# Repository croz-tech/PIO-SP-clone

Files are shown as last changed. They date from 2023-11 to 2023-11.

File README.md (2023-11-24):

# PIO-SP-clone
A clone of the 1980s Cambridge Microelectronics (Camel Products) PIO-SP providing 8 latched inputs and 8 latched outputs for the ZX Spectrum range of machines on port 63 (decimal).

# From the original User Notes
This parallel input/output card allows the Sinclair Spectrum personal computer to control external hardware such as relays, indicators, transducers and motors.
Eight output channels and eight input channels are provided.  Both channels employ latches to obtain stable readings.  They may be used for eight bit bytes or to read or control single independent devices.  PIO-SP is located in the Spectrum's I/O map at address 63 (decimal). Both ports have the same address so BASIC or machine code IN and OUT commands can be used.  For example, OUT 63,85 will put an alternate pattern of ones and zeroes at the output port.  The input port has provision for strobing-in the exteral data.  If data is meant to be continuously read in the Spectrum, without attention from the outside then the ~STB pin should be connected to GND (fit JP1).  The Spectrum strobes the input latch when executing an IN command and therefore reads whatever is present in the 8 bit latch, while strobing in the new data at the same time.  All inputs and outputs are TTL compatibe and have high drive capabilities.
The unit plugs into the rear of the Spectrum. (note this unit does not currently include the male pass-through edge connector of the original)
Header connections are identical to the Camel Products PIO for ZX81. For convenience, in addition to the DIP-16 headers, a 20-way IDC header is also provided for more convenient connection/disconnection.

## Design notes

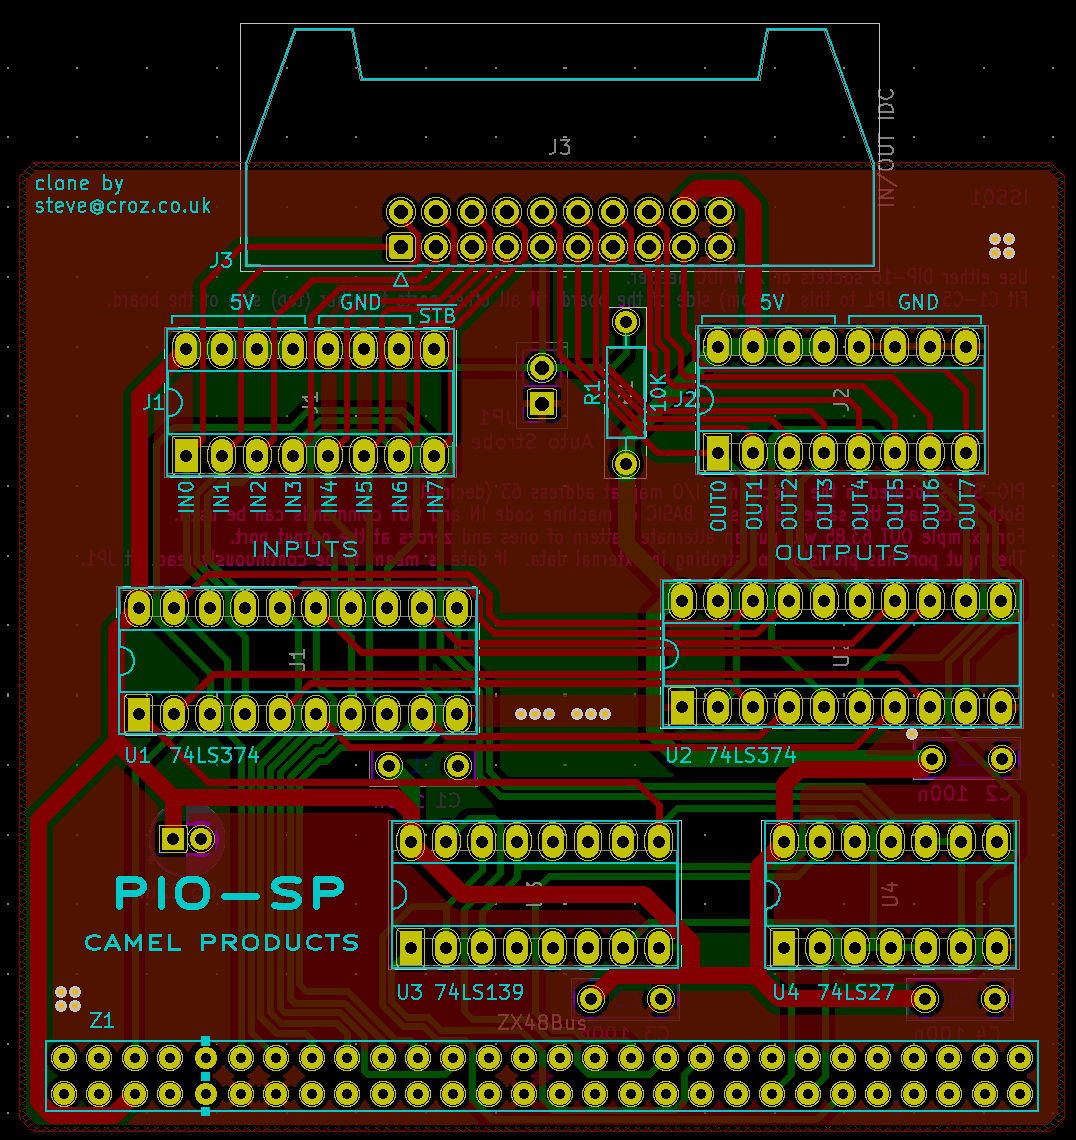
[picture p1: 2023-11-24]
PCB.png

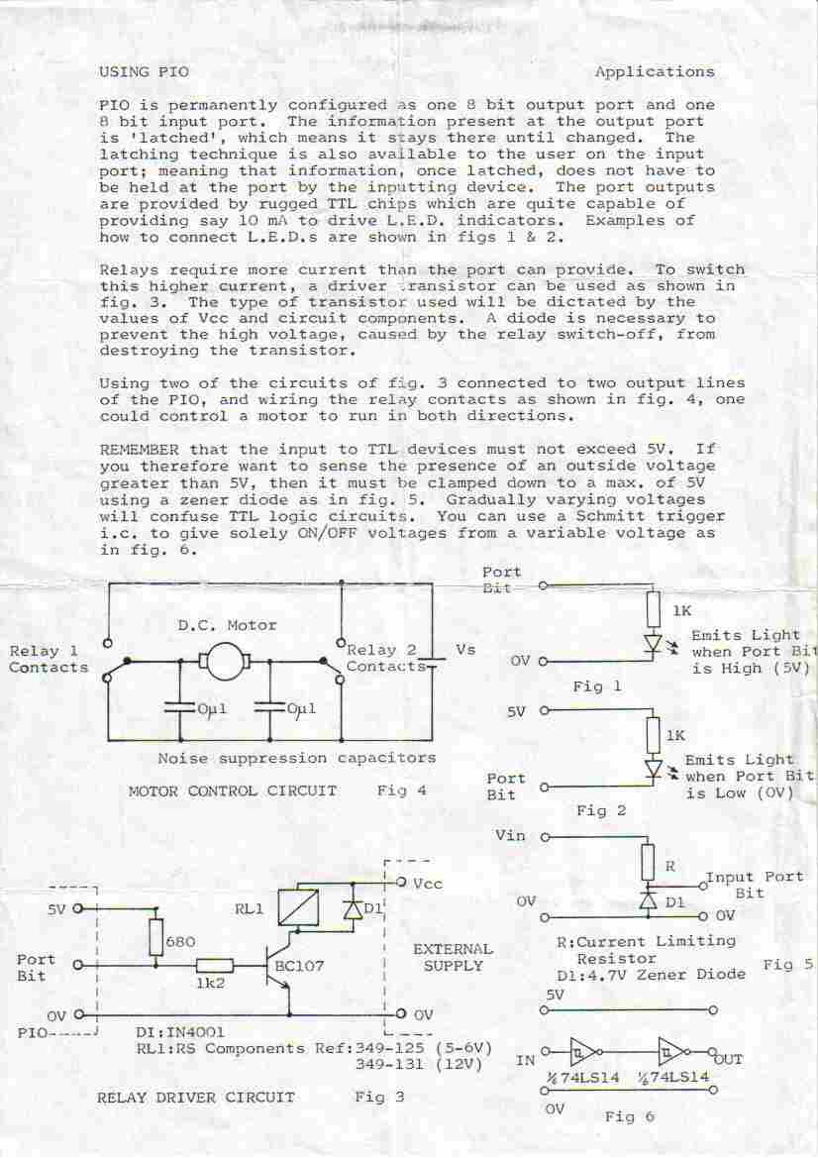
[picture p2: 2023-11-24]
original docs/Camel-PIO-SP-2.jpg

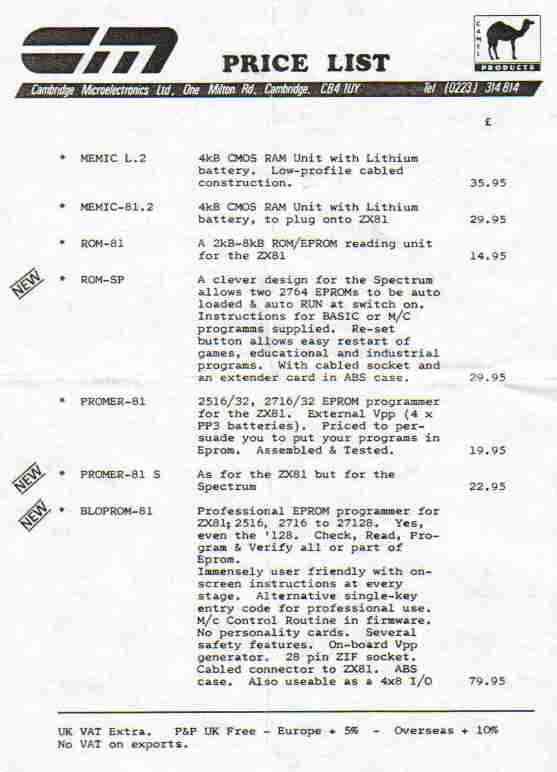
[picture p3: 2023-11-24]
original docs/Camel-Prices1.jpg

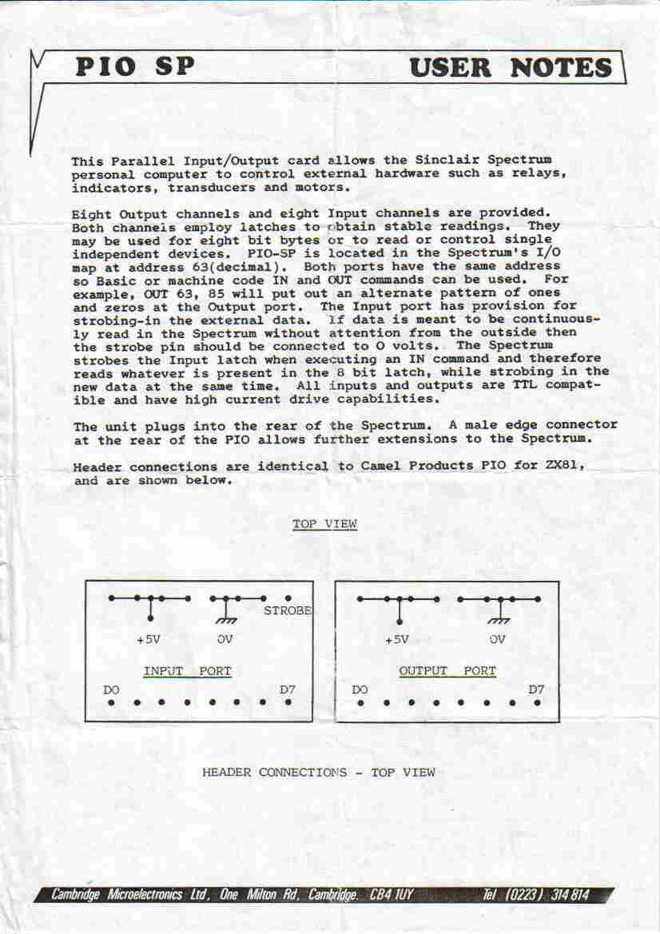
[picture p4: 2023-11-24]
original docs/Camel-PIO-SP-1.jpg

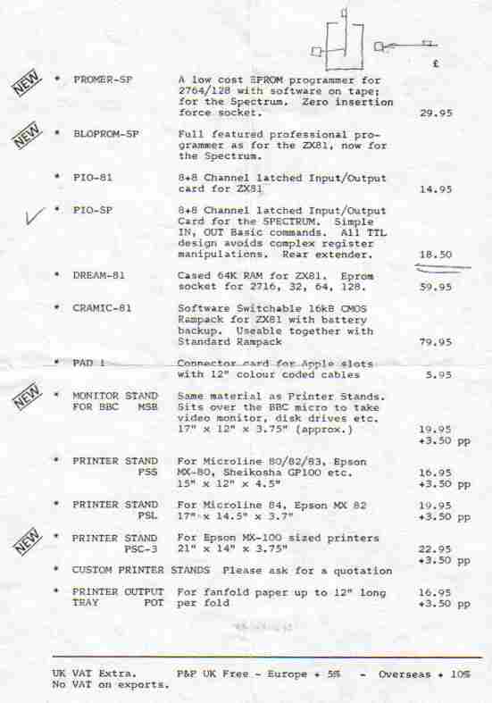
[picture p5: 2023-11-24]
original docs/Camel-Prices2.jpg

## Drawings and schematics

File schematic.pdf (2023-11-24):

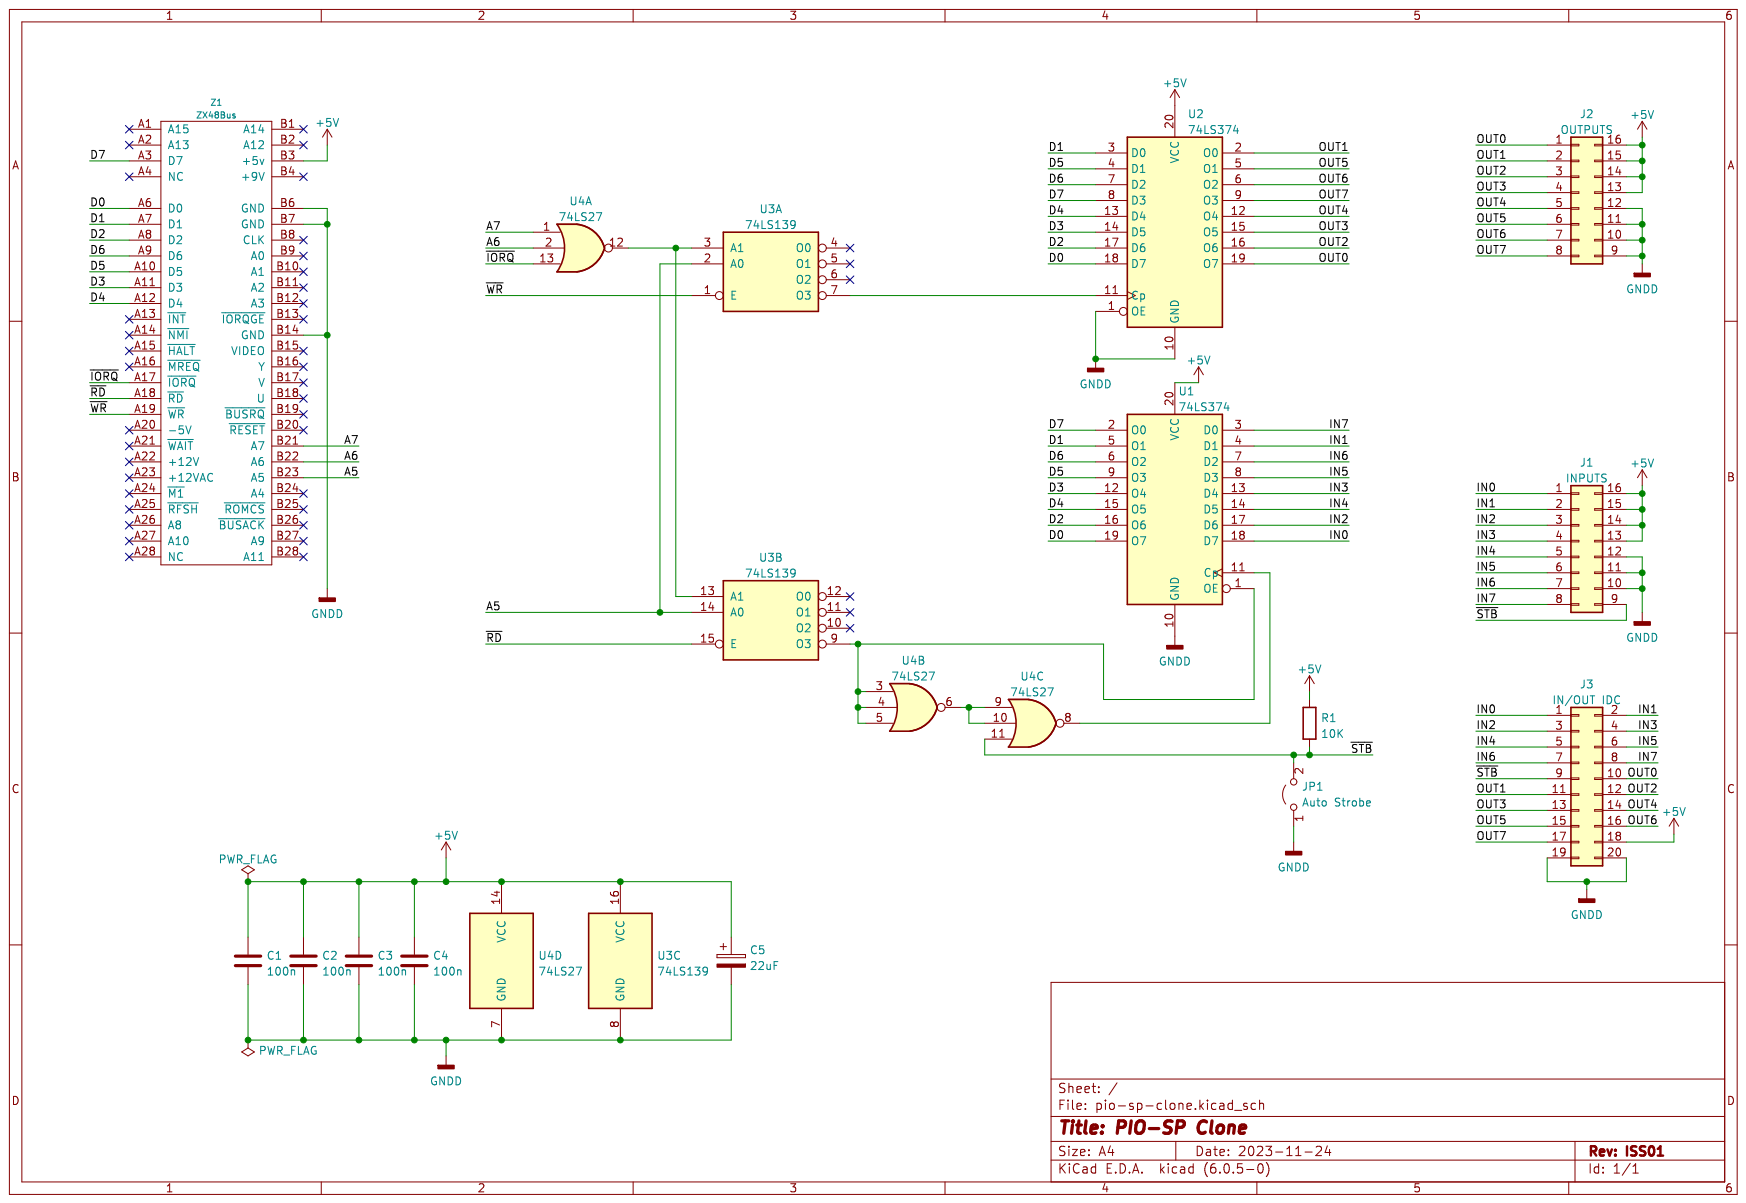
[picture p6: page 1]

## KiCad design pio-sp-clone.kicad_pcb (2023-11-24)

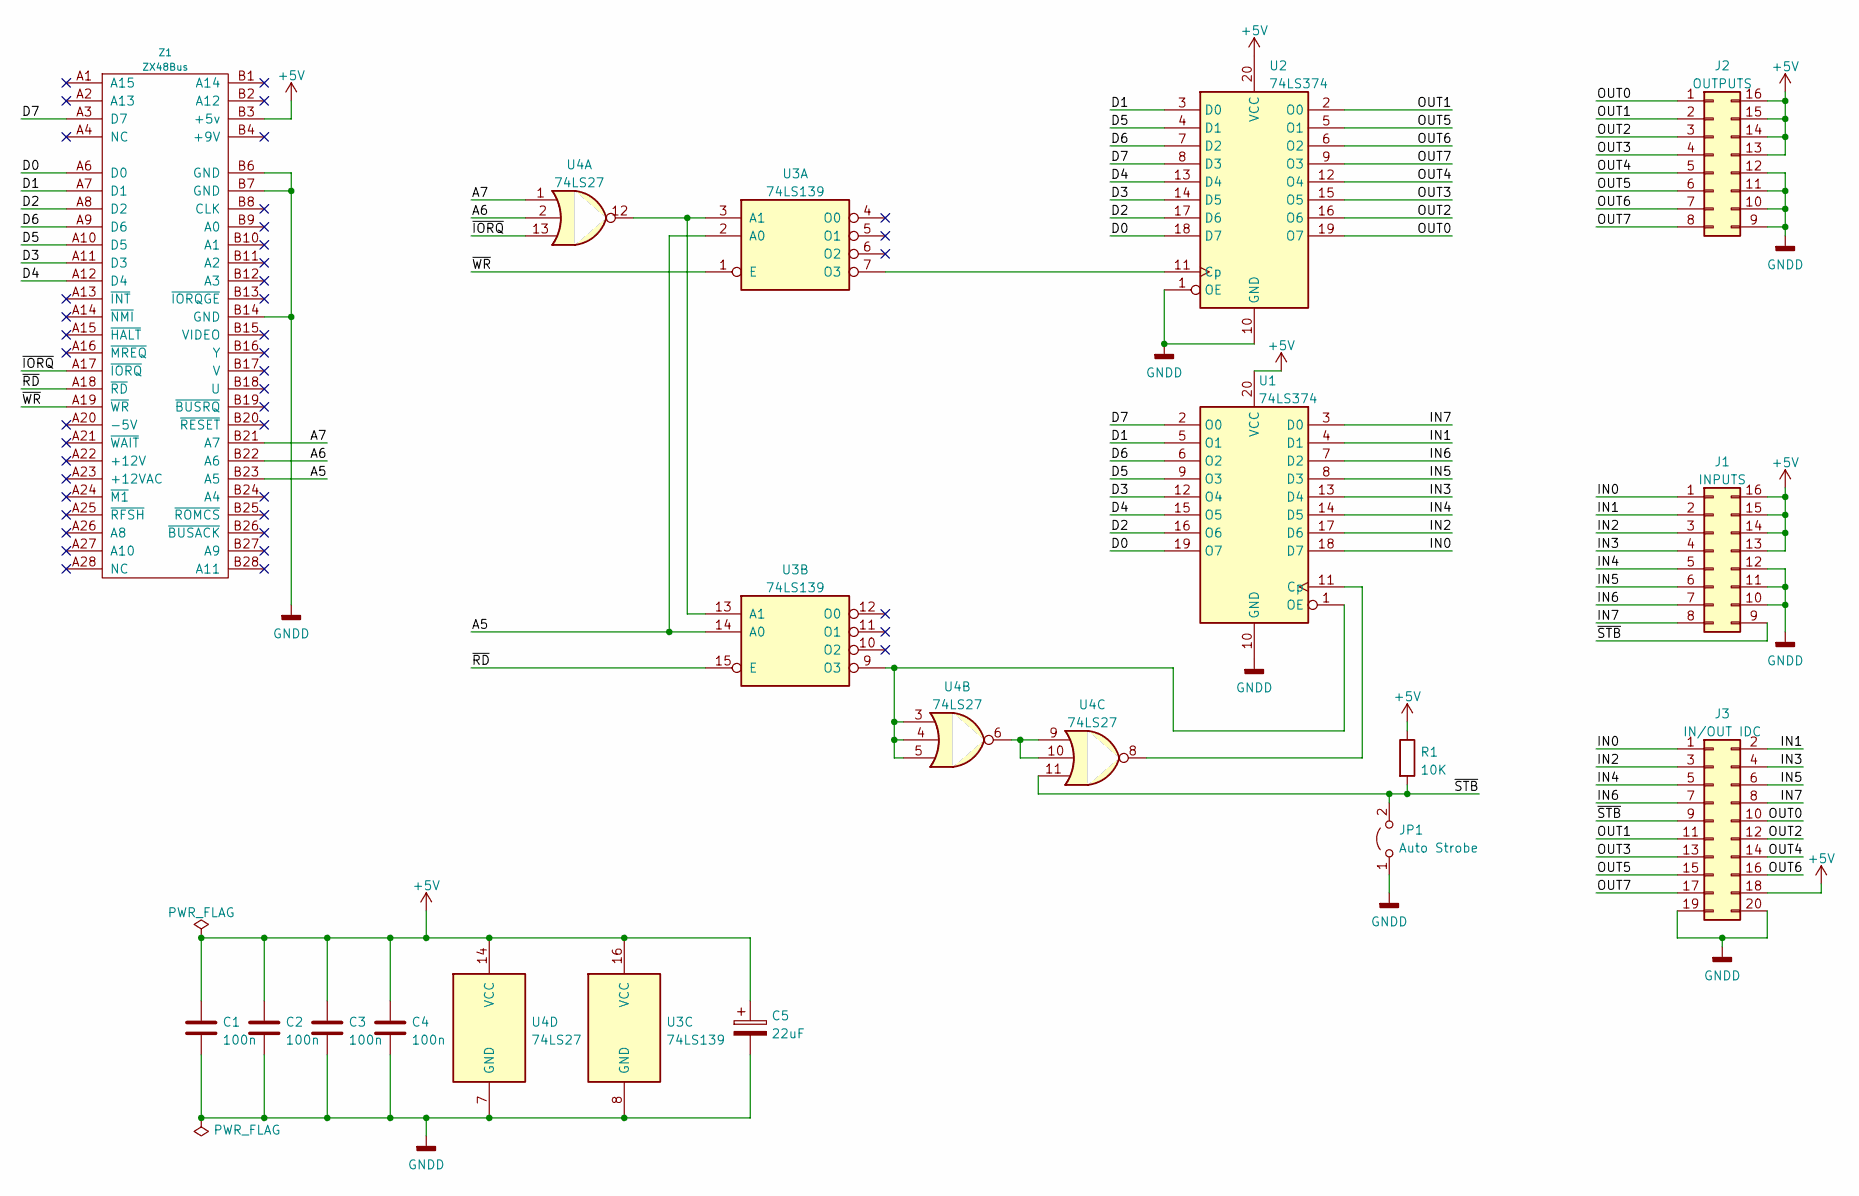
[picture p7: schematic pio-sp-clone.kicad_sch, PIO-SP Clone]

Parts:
C1, C2, C3, C4: 100n; C_Rect_L7.2mm_W2.5mm_P5.00mm_FKS2_FKP2_MKS2_MKP2
C5: 22uF; CP_Radial_D5.0mm_P2.00mm
J1: INPUTS; DIP-16_W7.62mm_Socket_LongPads
J2: OUTPUTS; DIP-16_W7.62mm_Socket_LongPads
J3: IN/OUT IDC; IDC-Header_2x10_P2.54mm_Latch_Horizontal
JP1: Auto Strobe; PinHeader_1x02_P2.54mm_Vertical
R1: 10K; R_Axial_DIN0207_L6.3mm_D2.5mm_P10.16mm_Horizontal
U1, U2: 74LS374; DIP-20_W7.62mm_Socket_LongPads
U3: 74LS139; DIP-16_W7.62mm_Socket_LongPads
U4: 74LS27; DIP-14_W7.62mm_Socket_LongPads
Z1: ZX48Bus; ZX_Bus_Pin_Header

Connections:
+5V: C1.1, C2.1, C3.1, C4.1, C5.1, J1.13, J1.14, J1.15, J1.16, J2.13, J2.14, J2.15, J2.16, J3.18, R1.1, U1.20 (VCC), U2.20 (VCC), U3.16 (VCC), U4.14 (VCC), Z1.B3 (+5v)
/A5: U3.2 (A0), U3.14 (A0), Z1.B23 (A5)
/A6: U4.2, Z1.B22 (A6)
/A7: U4.1, Z1.B21 (A7)
/D0: U1.19 (O7), U2.18 (D7), Z1.A6 (D0)
/D1: U1.5 (O1), U2.3 (D0), Z1.A7 (D1)
/D2: U1.16 (O6), U2.17 (D6), Z1.A8 (D2)
/D3: U1.12 (O4), U2.14 (D5), Z1.A11 (D3)
/D4: U1.15 (O5), U2.13 (D4), Z1.A12 (D4)
/D5: U1.9 (O3), U2.4 (D1), Z1.A10 (D5)
/D6: U1.6 (O2), U2.7 (D2), Z1.A9 (D6)
/D7: U1.2 (O0), U2.8 (D3), Z1.A3 (D7)
/IN0: J1.1, J3.1, U1.18 (D7)
/IN1: J1.2, J3.2, U1.4 (D1)
/IN2: J1.3, J3.3, U1.17 (D6)
/IN3: J1.4, J3.4, U1.13 (D4)
/IN4: J1.5, J3.5, U1.14 (D5)
/IN5: J1.6, J3.6, U1.8 (D3)
/IN6: J1.7, J3.7, U1.7 (D2)
/IN7: J1.8, J3.8, U1.3 (D0)
/OUT0: J2.1, J3.10, U2.19 (O7)
/OUT1: J2.2, J3.11, U2.2 (O0)
/OUT2: J2.3, J3.12, U2.16 (O6)
/OUT3: J2.4, J3.13, U2.15 (O5)
/OUT4: J2.5, J3.14, U2.12 (O4)
/OUT5: J2.6, J3.15, U2.5 (O1)
/OUT6: J2.7, J3.16, U2.6 (O2)
/OUT7: J2.8, J3.17, U2.9 (O3)
/~IORQ: U4.13, Z1.A17 (~IORQ)
/~RD: U3.15 (E), Z1.A18 (~RD)
/~STB: J1.9, J3.9, JP1.2 (B), R1.2, U4.11
/~WR: U3.1 (E), Z1.A19 (~WR)
GNDD: C1.2, C2.2, C3.2, C4.2, C5.2, J1.10, J1.11, J1.12, J2.9, J2.10, J2.11, J2.12, J3.19, J3.20, JP1.1 (A), U1.10 (GND), U2.1 (OE), U2.10 (GND), U3.8 (GND), U4.7 (GND), Z1.B6 (GND), Z1.B7 (GND), Z1.B14 (GND)
unnamed: U1.1 (OE), U3.9 (O3), U4.3, U4.4, U4.5
unnamed: U1.11 (Cp), U4.8
unnamed: U2.11 (Cp), U3.7 (O3)
unnamed: U3.3 (A1), U3.13 (A1), U4.12
unnamed: U4.6, U4.9, U4.10

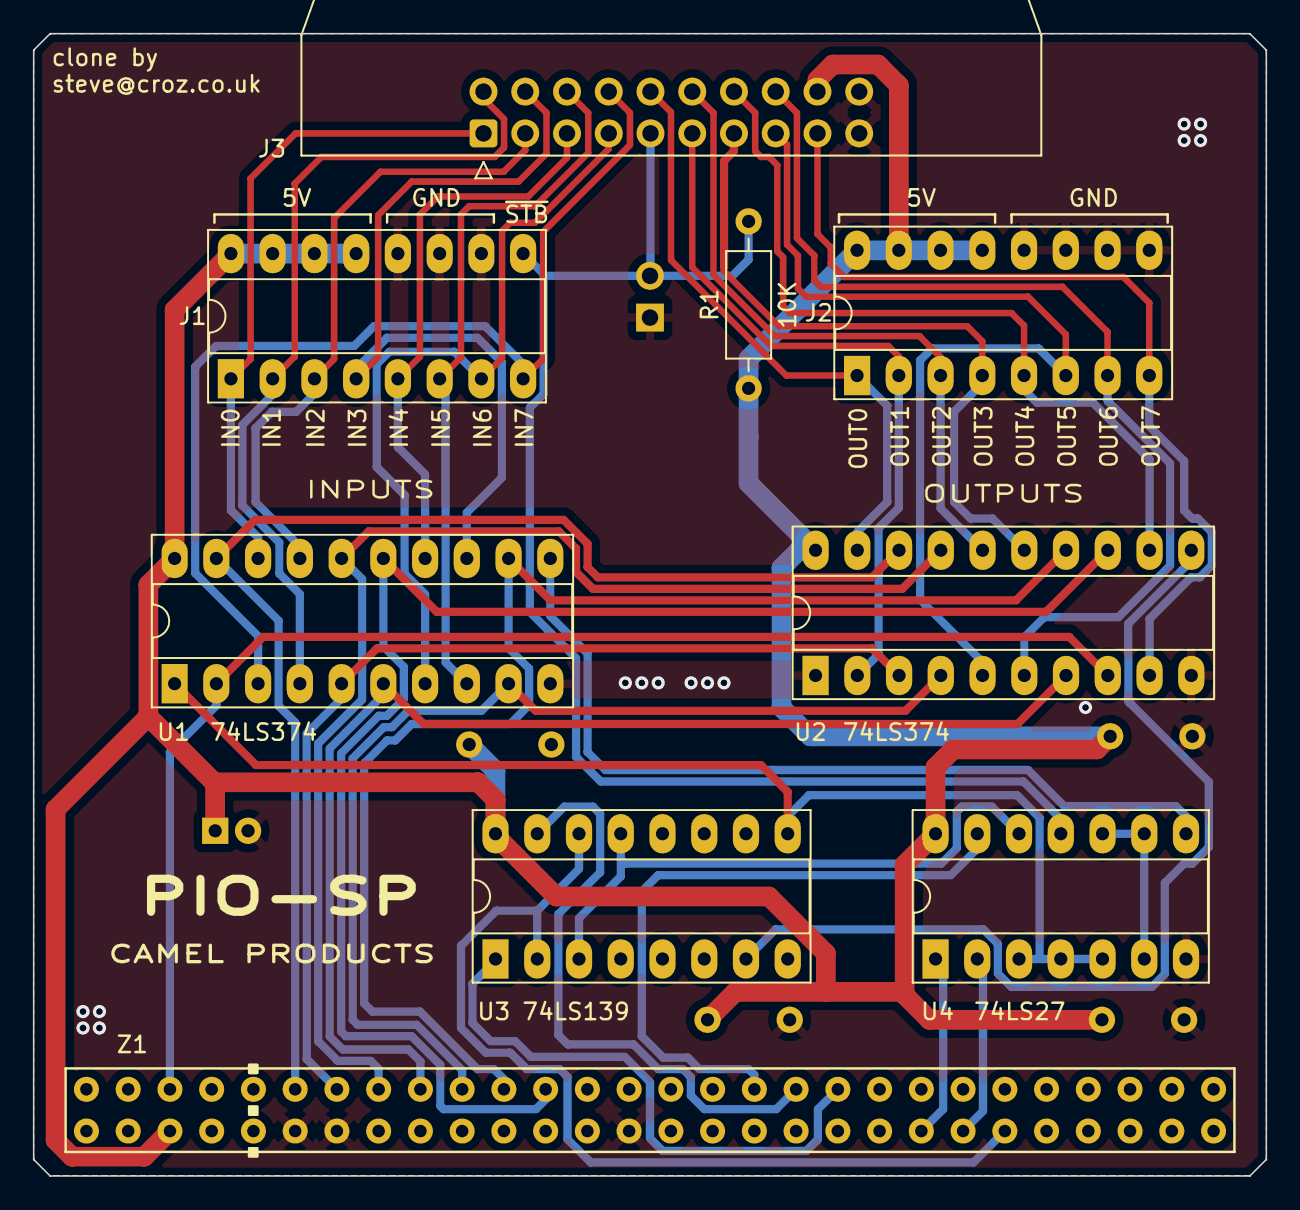
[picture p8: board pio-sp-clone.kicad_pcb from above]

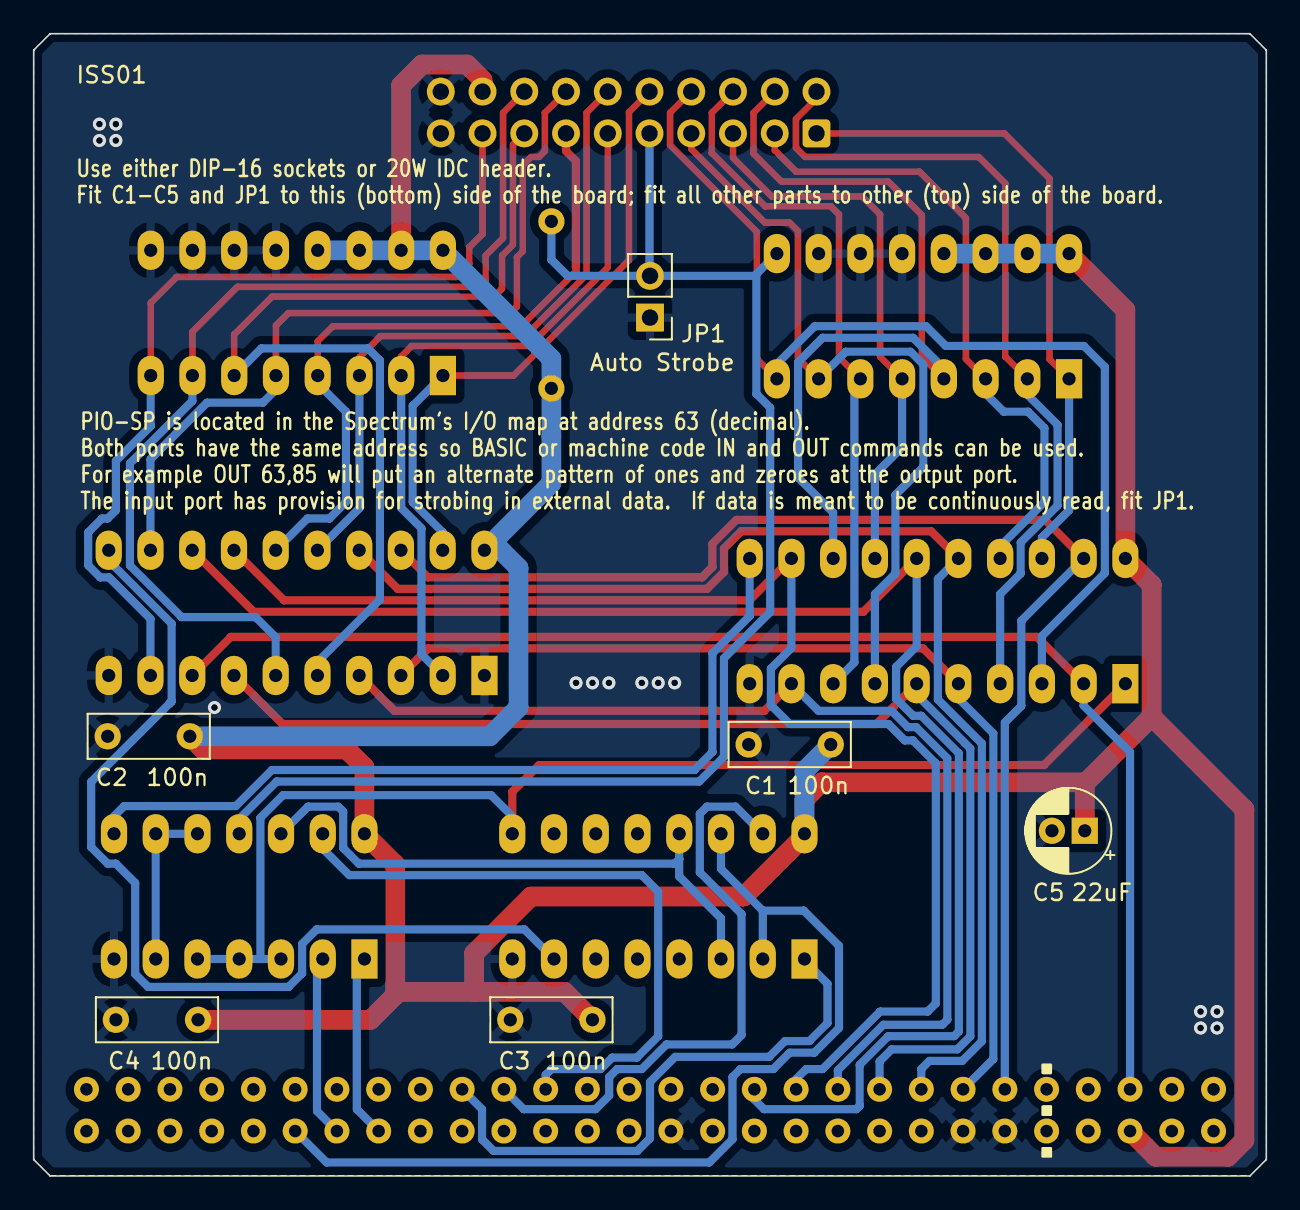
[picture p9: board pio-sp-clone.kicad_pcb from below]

Board: 2 copper layers, 75.0 x 69.5 mm, 15 parts (6 on the bottom side), 38 nets.
